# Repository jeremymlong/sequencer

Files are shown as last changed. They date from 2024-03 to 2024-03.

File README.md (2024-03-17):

# Sequencer
Inspired by the [LMNC Arduino 8 Step Sequencer Keyboard](https://www.lookmumnocomputer.com/sequencer-keyboard), but with several additional features.

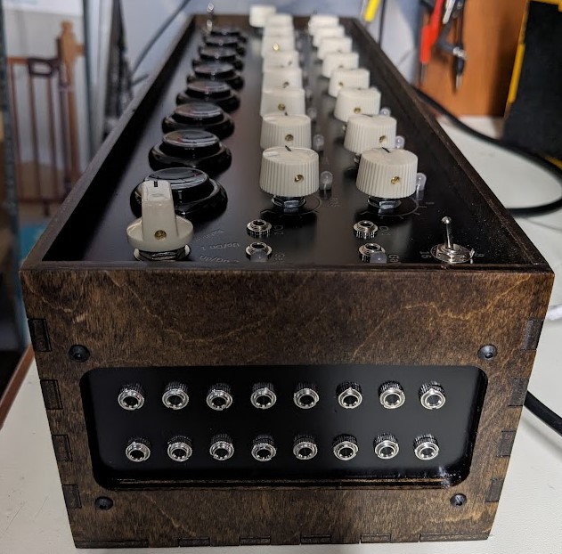
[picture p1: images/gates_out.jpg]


## Specs
 * 0 to 5V range
 * Arduino Nano based
 * Selectable dual 8 steps or 16 steps
 * Arcade button style keyboard
 * Internal or external clock
 * Gate on/off selectable for every step
 * Gate output for every step
 * Reset input and switch
 * Selectable patterns
    * Off
    * Forward
    * Backward
    * Random
    * 1-2-3-4-3-2
    * 1-2-3-4-4-3-2-1
    * Forward 2x (1-1-2-2-3-3-4-4)
    * Backward 2x (4-4-3-3-2-2-1-1)
    * Clockwise
    * Counterclockwise

## BOM
| Part | Quantity | Link |
|---|---|---|
| Arduino Nano | 1 | [Tayda](https://www.taydaelectronics.com/nano-3-0-controller-compatible-with-arduino-nano-usb-driver.html) |
| CD4051 | 1 | [Tayda](https://www.taydaelectronics.com/cd4051-4051-ic-cmos-multiplex-demultiplexer.html) |
| 74HC595 | 2 | [Tayda](https://www.taydaelectronics.com/74hc595-8-bit-shift-register-ic.html) |
| Arcade button | 8 | [Amazon](https://a.co/d/00wVvfu) |
| Mini toggle SPDT | 2 | [Tayda](https://www.taydaelectronics.com/mini-toggle-switch-spdt-on-on.html) |
| Mini toggle SPDT (momentary) | 2 | [Tayda](https://www.taydaelectronics.com/momentary-mini-toggle-switch-spdt-on-off-on.html) |
| Mini toggle DPDT | 1 | [Tayda](https://www.taydaelectronics.com/mini-toggle-switch-dpdt-on-on.html) |
| 100nF Capacitor | 3 | [Tayda](https://www.taydaelectronics.com/0-1uf-100v-5-polyester-film-box-type-capacitor.html) |
| 1N4148 diode | 23 | [Tayda](https://www.taydaelectronics.com/1n4148-switching-signal-diode.html) |
| 5mm WS2811 F5 LED | 20 | [AliExpress](https://www.aliexpress.us/item/2251832527100547.html?gatewayAdapt=glo2usa4itemAdapt), [ebay](https://www.ebay.com/itm/225210423475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) |
| 12 position rotary switch | 1 | [Tayda](https://www.taydaelectronics.com/rotary-switch-1-pole-12-position-alpha-sr2611f.html) |
| 1k Resistor | 1 | [Tayda](https://www.taydaelectronics.com/10-x-resistor-1k-ohm-1-4w-1-metal-film-pkg-of-10.html) |
| 2k Resistor | 11 | [Tayda](https://www.taydaelectronics.com/resistor-2k-ohm-1-4w-1-metal-film-pkg-of-10.html) |
| 10k Resistor | 1 | [Tayda](https://www.taydaelectronics.com/10-x-resistor-10k-ohm-1-4w-1-metal-film-pkg-of-10.html) |
| 100k Resistor | 2 | [Tayda](https://www.taydaelectronics.com/10-x-resistor-100k-ohm-1-4w-1-metal-film-pkg-of-10.html) |
| 470k Resistor | 2 | [Tayda](https://www.taydaelectronics.com/10-x-resistor-470k-ohm-1-4w-1-metal-film-pkg-of-10.html) |
| 100k potentiometer | 17 | [Tayda](https://www.taydaelectronics.com/tayda-100k-ohm-linear-taper-potentiometer-with-solder-lugs.html) (panel wiring) |
| Mono jack | 7 (23 for per gate output) | [Tayda](https://www.taydaelectronics.com/pj-3001f-3-5-mm-mono-phone-jack.html) (pcb), [Tayda](https://www.taydaelectronics.com/3-5mm-earphone-mono-plug.html) (panel wiring) |
| Knobs | 18 |

## TODO
 * Arp when more than 1 button is held
 * Adjustable gate length

## Arduino Dependencies
 * [Adafruit_NeoPixel](https://github.com/adafruit/Adafruit_NeoPixel)

## Note about the schematic and board
Because this is big, I only did a small PCB for this. This is why there are random components floating above the board. For the remaining components (pots, buttons, switches, LEDs) I wired them old school with panel wiring. It was a great reminder why it's so much better to use a PCB for that instead.

## Note about 12 position switch
The 12 position switch is not on the schematic. It's wired like a potentiometer, with the 11 2k resistors between the positions. There are several tutorials on how to do this.

## Note about LEDs
The LEDs are not included on the schematic. I directly mounted the LEDs to the panel with hot glue and wired them point to point. Wires are connected to the leads of the first LED. The LEDs need to be wired in a particular order, as follows:
1. Step 1
1. Step 2
1. Step 3
1. Step 4
1. Step 5
1. Step 6
1. Step 7
1. Step 8
1. Step 16
1. Step 15
1. Step 14
1. Step 13
1. Step 12
1. Step 11
1. Step 10
1. Step 9
1. Clock out
1. Clock in
1. Gate A
1. Gate B

## Note about power
This really needs a clean power source. I'm powering mine from my rack's supply. If I power it from a regular cheap 5V switching adapter, it's noisy.

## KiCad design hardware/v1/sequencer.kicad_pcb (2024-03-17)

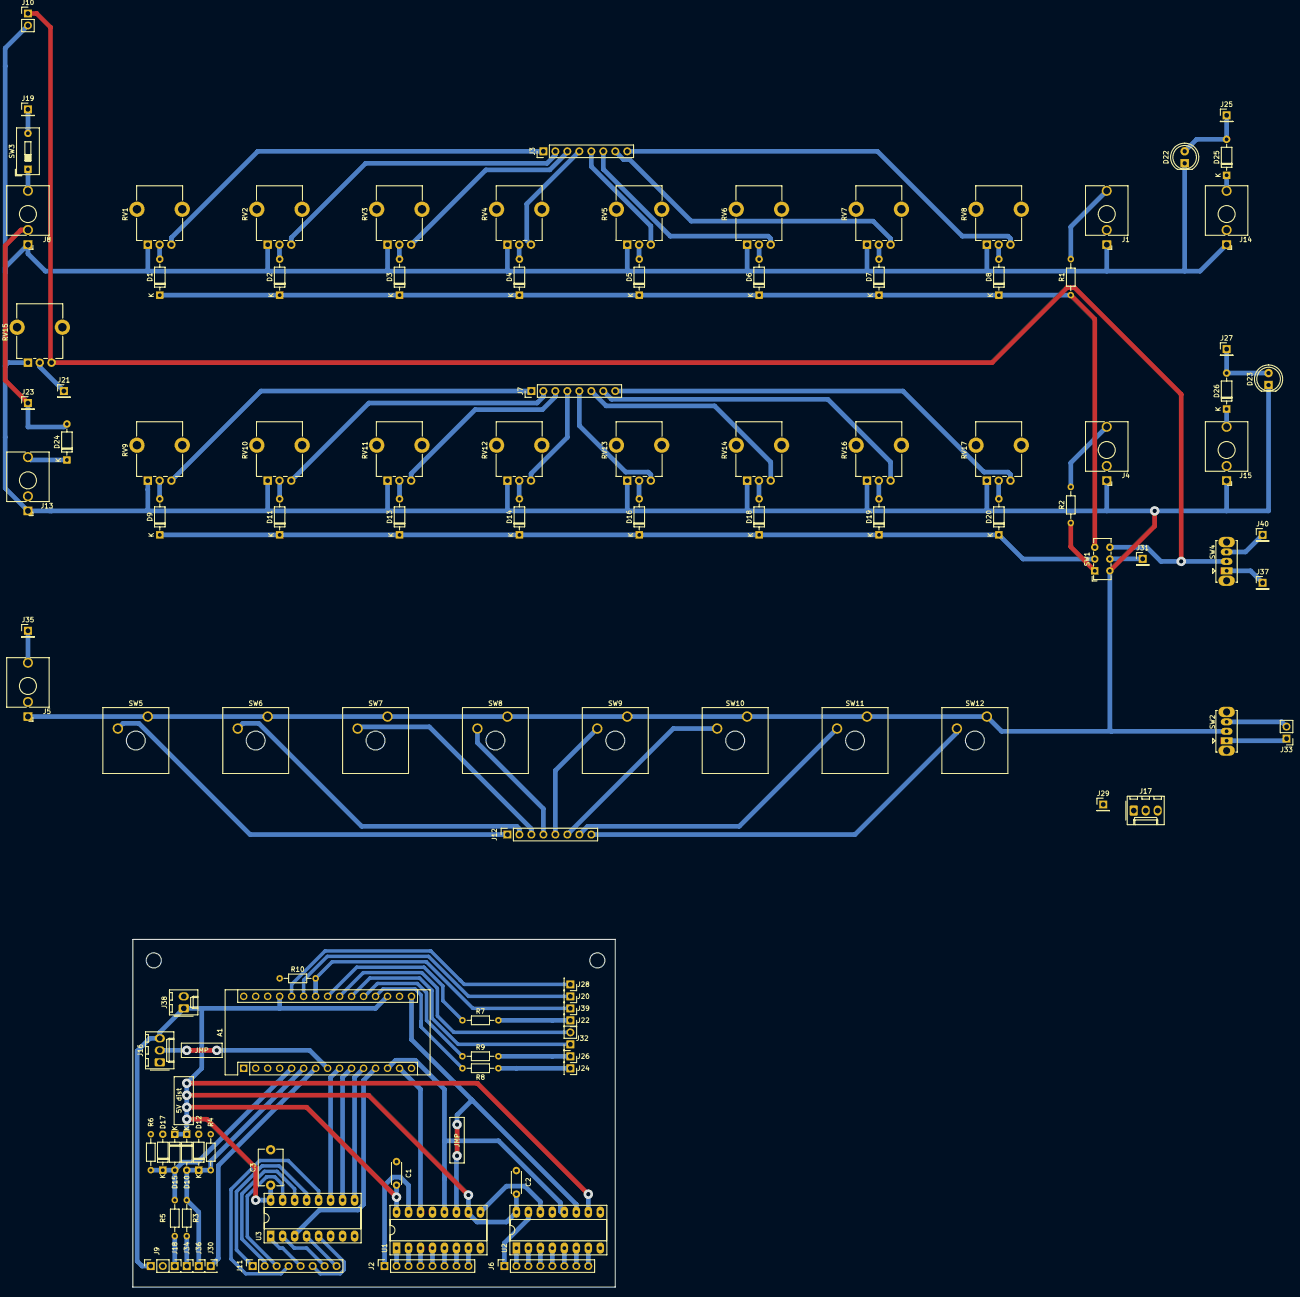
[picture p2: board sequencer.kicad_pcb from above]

Board: 2 copper layers, 102.2 x 73.7 mm, 111 parts (0 on the bottom side), 113 nets.

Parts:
A1: Arduino_Nano_v3.x; Arduino_Nano
C1, C2: 100nF; C_Disc_D4.3mm_W1.9mm_P5.00mm
C3: 100nF; C_Disc_D7.5mm_W5.0mm_P7.50mm
D1, D2, D3, D4, D5, D6, D7, D8, D9, D10, D11, D12, D13, D14, D15, D16, D17, D18, D19, D20, D24, D25, D26: 1N4148; D_DO-35_SOD27_P7.62mm_Horizontal
D22, D23: LED; LED_D5.0mm
J1: CV A OUT; Jack_3.5mm_QingPu_WQP-PJ398SM_Vertical_CircularHoles
J2: seq_a_board; PinSocket_1x08_P2.54mm_Vertical
J3: seq_a_panel; PinHeader_1x08_P2.54mm_Vertical
J4: CV B OUT; Jack_3.5mm_QingPu_WQP-PJ398SM_Vertical_CircularHoles
J5: RESET_IN; Jack_3.5mm_QingPu_WQP-PJ398SM_Vertical_CircularHoles
J6: seq_b_board; PinSocket_1x08_P2.54mm_Vertical
J7: seq_b_panel; PinHeader_1x08_P2.54mm_Vertical
J8: CLOCK_IN; Jack_3.5mm_QingPu_WQP-PJ398SM_Vertical_CircularHoles
J9: power_board; PinSocket_1x02_P2.54mm_Vertical
J10: power_panel; PinHeader_1x02_P2.54mm_Vertical
J11: keys_board; PinSocket_1x08_P2.54mm_Vertical
J12: keys_panel; PinSocket_1x08_P2.54mm_Vertical
J13: CLOCK_OUT; Jack_3.5mm_QingPu_WQP-PJ398SM_Vertical_CircularHoles
J14: GATE A; Jack_3.5mm_QingPu_WQP-PJ398SM_Vertical_CircularHoles
J15: GATE B; Jack_3.5mm_QingPu_WQP-PJ398SM_Vertical_CircularHoles
J16: leds_board; Molex_KK-254_AE-6410-03A_1x03_P2.54mm_Vertical
J17: leds_wire; Molex_KK-254_AE-6410-03A_1x03_P2.54mm_Vertical
J18: CLK IN; PinSocket_1x01_P2.54mm_Vertical
J19, J21, J23, J25, J27, J29, J31, J35, J37, J40: panel; PinHeader_1x01_P2.54mm_Vertical
J20: CLK RATE; PinSocket_1x01_P2.54mm_Vertical
J22: CLK OUT; PinSocket_1x01_P2.54mm_Vertical
J24: GATE A; PinSocket_1x01_P2.54mm_Vertical
J26: GATE B; PinSocket_1x01_P2.54mm_Vertical
J28: SEQ MODE; PinSocket_1x01_P2.54mm_Vertical
J30: STEP CNT; PinSocket_1x01_P2.54mm_Vertical
J32: GATE PGM; PinSocket_1x02_P2.54mm_Vertical
J33: gate_pgm_panel; PinHeader_1x02_P2.54mm_Vertical
J34: RESET; PinSocket_1x01_P2.54mm_Vertical
J36: RST SW; PinSocket_1x01_P2.54mm_Vertical
J38: power_board_input; Molex_KK-254_AE-6410-02A_1x02_P2.54mm_Vertical
J39: STEP CNT SW; PinSocket_1x01_P2.54mm_Vertical
R1, R2, R7, R8, R9: 1k; R_Axial_DIN0204_L3.6mm_D1.6mm_P7.62mm_Horizontal
R3, R5: 100k; R_Axial_DIN0204_L3.6mm_D1.6mm_P7.62mm_Horizontal
R4, R6: 470k; R_Axial_DIN0204_L3.6mm_D1.6mm_P7.62mm_Horizontal
R10: 10k; R_Axial_DIN0204_L3.6mm_D1.6mm_P7.62mm_Horizontal
RV1: STEP1; Potentiometer_Alpha_RD901F-40-00D_Single_Vertical_CircularH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
RV2: STEP2; Potentiometer_Alpha_RD901F-40-00D_Single_Vertical_CircularH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
RV3: STEP3; Potentiometer_Alpha_RD901F-40-00D_Single_Vertical_CircularH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
RV4: STEP4; Potentiometer_Alpha_RD901F-40-00D_Single_Vertical_CircularH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
RV5: STEP5; Potentiometer_Alpha_RD901F-40-00D_Single_Vertical_CircularH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
RV6: STEP6; Potentiometer_Alpha_RD901F-40-00D_Single_Vertical_CircularH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
RV7: STEP7; Potentiometer_Alpha_RD901F-40-00D_Single_Vertical_CircularH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
RV8: STEP8; Potentiometer_Alpha_RD901F-40-00D_Single_Vertical_CircularH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
RV9: STEP1/9; Potentiometer_Alpha_RD901F-40-00D_Single_Vertical_CircularH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
RV10: STEP2/10; Potentiometer_Alpha_RD901F-40-00D_Single_Vertical_CircularH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
RV11: STEP3/11; Potentiometer_Alpha_RD901F-40-00D_Single_Vertical_CircularH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
RV12: STEP4/12; Potentiometer_Alpha_RD901F-40-00D_Single_Vertical_CircularH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
RV13: STEP5/13; Potentiometer_Alpha_RD901F-40-00D_Single_Vertical_CircularH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
RV14: STEP6/14; Potentiometer_Alpha_RD901F-40-00D_Single_Vertical_CircularH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
RV15: CLOCK; Potentiometer_Alpha_RD901F-40-00D_Single_Vertical_CircularH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
RV16: STEP7/15; Potentiometer_Alpha_RD901F-40-00D_Single_Vertical_CircularH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
RV17: STEP8/16; Potentiometer_Alpha_RD901F-40-00D_Single_Vertical_CircularH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
SW1: SW_DPDT_x2; SW_E-Switch_EG1271_DPDT
SW2, SW4: SW_SPDT_MSM; SW_Slide_1P2T_CK_OS102011MS2Q
SW3: SW_SPST; SW_DIP_SPSTx01_Slide_9.78x4.72mm_W7.62mm_P2.54mm
SW5, SW6, SW7, SW8, SW9, SW10, SW11, SW12: SW_Push; SW_Cherry_MX_1.00u_Plate
U1, U2: 74HC595; DIP-16_W7.62mm_Socket_LongPads
U3: 4051; DIP-16_W7.62mm_Socket_LongPads

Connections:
+5V: A1.18, A1.27, C1.1, C2.1, C3.1, D10.1, D15.1, J9.1, J16.3, J38.1, U1.10, U1.16, U2.10, U2.16, U3.16
+5VA: J10.1, RV15.3, SW1.6, SW4.2
GND: A1.4, A1.29, C1.2, C2.2, C3.2, D12.2, D17.2, J9.2, J16.1, J38.2, R4.1, R6.1, R10.1, U1.8, U1.13, U2.8, U2.13, U3.6, U3.7, U3.8
GNDA: D22.1, D23.1, J1.S, J4.S, J5.S, J8.S, J10.2, J13.S, J14.S, J15.S, RV1.1, RV2.1, RV3.1, RV4.1, RV5.1, RV6.1, RV7.1, RV8.1, RV9.1, RV10.1, RV11.1, RV12.1, RV13.1, RV14.1, RV15.1, RV16.1, RV17.1, SW1.4, SW2.2, SW5.1, SW6.1, SW7.1, SW8.1, SW9.1, SW10.1, SW11.1, SW12.1
MOSI: A1.14, U1.14
unnamed: D1.1, D2.1, D3.1, D4.1, D5.1, D6.1, D7.1, D8.1, R1.1, SW1.3
unnamed: D1.2, RV1.2
unnamed: D2.2, RV2.2
unnamed: D3.2, RV3.2
unnamed: D4.2, RV4.2
unnamed: D5.2, RV5.2
unnamed: D6.2, RV6.2
unnamed: D7.2, RV7.2
unnamed: D8.2, RV8.2
unnamed: D9.2, RV9.2
unnamed: D9.1, D11.1, D13.1, D14.1, D16.1, D18.1, D19.1, D20.1, SW1.2
unnamed: D11.2, RV10.2
unnamed: D13.2, RV11.2
unnamed: D14.2, RV12.2
unnamed: D16.2, RV13.2
unnamed: D18.2, RV14.2
unnamed: D19.2, RV16.2
unnamed: D20.2, RV17.2
unnamed: D22.2, D25.2, J25.1
unnamed: D23.2, D26.2, J27.1
unnamed: D24.1, J13.T
unnamed: D24.2, J8.TN, J23.1
unnamed: D25.1, J14.T
unnamed: D26.1, J15.T
unnamed: J1.T, R1.2
unnamed: J2.1, U1.15
unnamed: J2.2, U1.1
unnamed: J2.3, U1.2
unnamed: J2.4, U1.3
unnamed: J2.5, U1.4
unnamed: J2.6, U1.5
unnamed: J2.7, U1.6
unnamed: J2.8, U1.7
unnamed: J3.1, RV1.3
unnamed: J3.2, RV2.3
unnamed: J3.3, RV3.3
unnamed: J3.4, RV4.3
unnamed: J3.5, RV5.3
unnamed: J3.6, RV6.3
unnamed: J3.7, RV7.3
unnamed: J3.8, RV8.3
unnamed: J4.T, R2.2
unnamed: J6.1, U2.15
unnamed: J6.2, U2.1
unnamed: J6.3, U2.2
unnamed: J6.4, U2.3
unnamed: J6.5, U2.4
unnamed: J6.6, U2.5
unnamed: J6.7, U2.6
unnamed: J6.8, U2.7
unnamed: J7.1, RV9.3
unnamed: J7.2, RV10.3
unnamed: J7.3, RV11.3
unnamed: J7.4, RV12.3
unnamed: J7.5, RV13.3
unnamed: J7.6, RV14.3
unnamed: J7.7, RV16.3
unnamed: J7.8, RV17.3
unnamed: J8.T, SW3.1
unnamed: J11.1, U3.13
unnamed: J11.2, U3.14
unnamed: J11.3, U3.15
unnamed: J11.4, U3.12
unnamed: J11.5, U3.1
unnamed: J11.6, U3.5
unnamed: J11.7, U3.2
unnamed: J11.8, U3.4
unnamed: J12.1, SW5.2
unnamed: J12.2, SW6.2
unnamed: J12.3, SW7.2
unnamed: J12.4, SW8.2
unnamed: J12.5, SW9.2
unnamed: J12.6, SW10.2
unnamed: J12.7, SW11.2
unnamed: J12.8, SW12.2
unnamed: J18.1, R5.2
unnamed: J19.1, SW3.2
unnamed: J21.1, RV15.2
unnamed: J22.1, R7.2
unnamed: J24.1, R8.2
unnamed: J26.1, R9.2
unnamed: J31.1, SW1.5
unnamed: J33.1, SW2.1
unnamed: J33.2, SW2.3
unnamed: J34.1, R3.2
unnamed: J5.T, J35.1
unnamed: J37.1, SW4.1
unnamed: J40.1, SW4.3
unnamed: R2.1, SW1.1
unnamed: U1.9, U2.14
SCK: A1.16, U1.11, U2.11
clock_in: A1.5, D15.2, D17.1, R5.1, R6.2
clock_out: A1.23, R7.1
clock_rate: A1.25, J20.1
gate_a_program: A1.21, J32.1
gate_b_program: A1.22, J32.2
gate_output_a: A1.19, R8.1
gate_output_b: A1.20, R9.1
key_input: A1.12, U3.3
key_s0: A1.9, U3.11
key_s1: A1.10, U3.10
key_s2: A1.11, U3.9
led_data_out: A1.8, J16.2
select_595: A1.13, U1.12, U2.12
sequence_mode: A1.26, J28.1
sequence_reset: A1.6, D10.2, D12.1, J36.1, R3.1, R4.2
step_count: A1.7, J30.1
step_count_program: A1.24, J39.1, R10.2

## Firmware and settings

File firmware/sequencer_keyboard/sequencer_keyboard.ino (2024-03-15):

#pragma once
#include "src/pin_definitions.h"
#include "src/leds.h"
#include "src/clock_out.h"
#include "src/sequencer.h"


sk::leds leds;
sk::clock_out clock_out(leds);
sk::sequencer sequencer(leds);

volatile bool reset_triggered{};
volatile bool clock_triggered{};

void loop_low_priority();

void setup() {
    #ifdef DEBUG
    Serial.begin(115200);
    #endif
    pinMode(sk::pins::sequence_reset, INPUT);
    pinMode(sk::pins::clock_input, INPUT);
    attachInterrupt(digitalPinToInterrupt(sk::pins::sequence_reset), [] {reset_triggered = true; }, RISING);
    attachInterrupt(digitalPinToInterrupt(sk::pins::clock_input), []{ clock_triggered = true; }, CHANGE);
    SPI.begin();
    clock_out.triggered = loop_low_priority;
    sequencer.begin();
}

void loop()  {
    // high priority loop
    clock_out.loop();
    sequencer.loop();

    if (clock_triggered) {
        clock_triggered = false;
        
        bool clock_input_state = digitalRead(sk::pins::clock_input);
        leds.display_clock_input(clock_input_state);

        if (clock_input_state) {
            sequencer.trigger();
        }
        sequencer.gate_update(clock_input_state);
    }
    if (reset_triggered) {
        reset_triggered = false;
        sequencer.reset();
    }
}

void loop_low_priority() {
    // low priority loop
    sequencer.loop_low_priority(digitalRead(sk::pins::clock_input));
}

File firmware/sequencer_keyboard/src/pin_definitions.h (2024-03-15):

#pragma once
#include <Arduino.h>


namespace sk {
namespace pins {
    static const int clock_output = A4;
    static const int clock_rate_pot = A6;
    static const int clock_input = 2;

    static const int sequence_reset = 3;
    static const int sequencer_output_select = 10;
    static const int sequence_mode = A7;
    
    static const int keyboard_input = 9;
    static const int keyboard_s0 = 6;
    static const int keyboard_s1 = 7;
    static const int keyboard_s2 = 8;

    static const int gate_output_a = A0;
    static const int gate_output_b = A1;
    static const int gate_program_a = A2;
    static const int gate_program_b = A3;

    static const int step_count = 4;
    static const int step_count_program = A5;

    static const int led_data_output = 5;
}
}

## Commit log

2024-03-17 Added readme
    [sequencer.kicad_pcb, sequencer.sch]
2024-03-17 Added gates image and power note to README
2024-03-17 Added note about board/schematic to README
